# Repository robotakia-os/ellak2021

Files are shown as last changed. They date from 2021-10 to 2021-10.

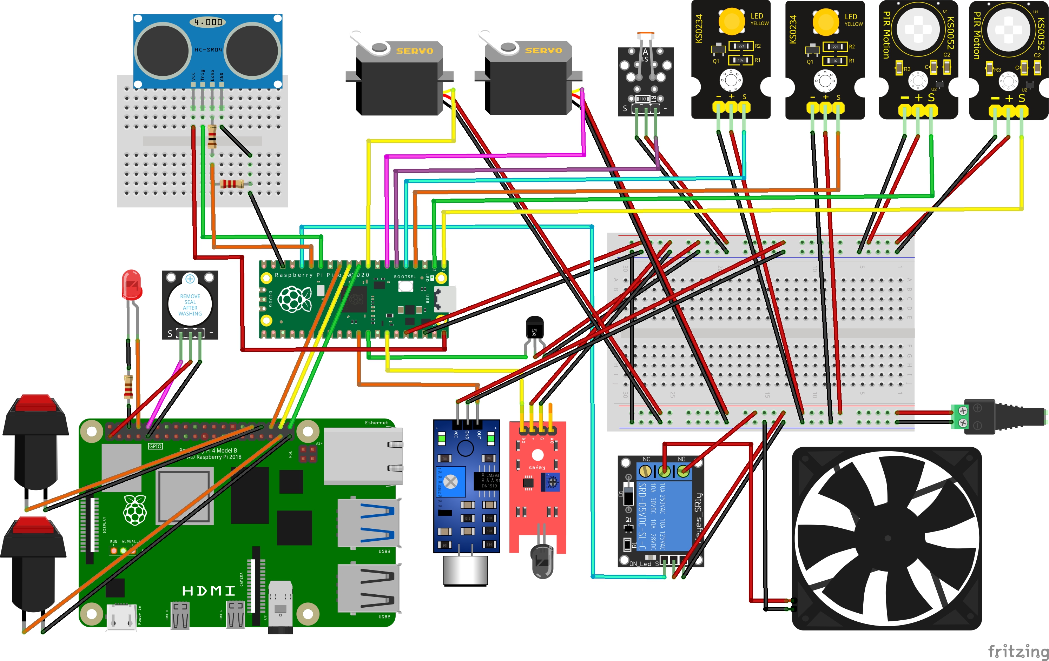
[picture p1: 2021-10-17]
σχηματικό-συνδεσμολογία/schematic.jpg

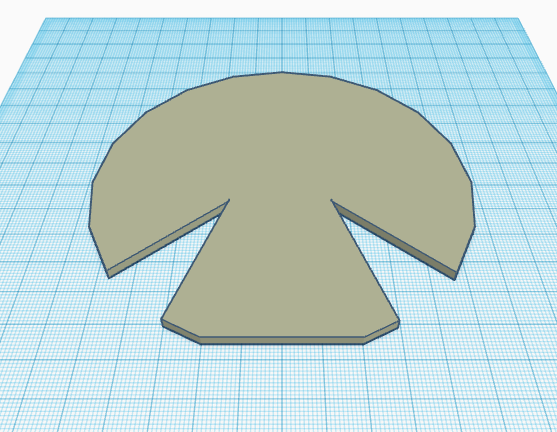
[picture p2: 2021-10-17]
3d printing/plate.png

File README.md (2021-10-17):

# ellak2021
3ος Πανελλήνιος Διαγωνισμός Ανοιχτών Τεχνολογιών στην Εκπαίδευση (2021)

Η ομάδα μας υλοποίησε μία μακέτα ενός ευφυούς σπιτιού φιλικό προς τα κατοικίδια. Στην εργασία περιλαμβάνονται οι παρακάτω προτάσεις/λύσεις:

•	Ενεργοποίηση του συστήματος φωτισμού σε συγκεκριμένους χώρους του σπιτιού και όταν αυτό κρίνεται απαραίτητο (μέρα/νύχτα).

•	Δημιουργία πόρτας διαφυγής του κατοικίδιου σε περίπτωση πυρκαγιάς.

•	Αναπαραγωγή χαλαρής μουσικής σε περίπτωση δυνατών ήχων που μπορεί να τρομάξουν το κατοικίδιο (βροντές κ.ά.).

•	Ενεργοποίηση εξαερισμού όταν η θερμοκρασία ανέβει σε υψηλά επίπεδα.

•	Σύστημα παροχής τροφής βασισμένο στην αναγνώριση αντικειμένων, το οποίο μπορεί να διακρίνει αν το κατοικίδιο είναι γάτα ή σκύλος. Το σύστημα ενεργοποιείται μόλις το κατοικίδιο πλησιάσει την τροφή του και σε προκαθορισμένα χρονικά διαστήματα.

•	Σύστημα συναγερμού το οποίο βασίζεται στην αναγνώριση αντικειμένων. Πιο συγκεκριμένα, ο συναγερμός ενεργοποιείται μόλις κάποιος άνθρωπος καταγραφεί από την κάμερα του συστήματος και όχι από κάποιον αισθητήρα PIR.

Η ιστοσελίδα του έργου μας: https://openedtech.ellak.gr/robotics2021/robotakia-open-source-effies-spiti-filiko-pros-ta-katikidia/

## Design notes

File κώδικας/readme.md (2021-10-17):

Το αρχείο pico_code.py είναι αυτό που εκτελείται από το Raspberry Pi Pico και το αρχείο pi4_code.py εκτελείται  στο Raspberry Pi 4.

Ο κώδικας που τρέχει στο Pico δημιουργήθηκε εξαρχής από την ομάδα μας. Αν μετονομαστεί το αρχείο σε main.py και αποθηκευτεί στο Pico και όχι στον υπολογιστή, θα τρέχει κατευθείαν μόλις το Pico τροφοδοτηθεί με 5V.

Στα αρχικά σχόλια του προγράμματος pi4_code.py περιγράφονται τα σημεία που τροποποιήσαμε τον κώδικα που χρησιμοποιήσαμε.

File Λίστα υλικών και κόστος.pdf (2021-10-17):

Το συνολικό κόστος υλοποίησης της μακέτας δεν ξεπερνά τα 100€, συμπεριλαμβανομένων των δευτερευόντων υλικών (μακετόχαρτα, θερμόκολλες κ.ά.) και όλα τα ηλεκτρονικά εξαρτήματα μπορούν να επαναχρησιμοποιηθούν σε μελλοντικό project. Το κόστος μπορεί να περιοριστεί ακόμα περισσότερο αν χρησιμοποιηθούν βασικότεροι αισθητήρες σε συνδυασμό με τα απαραίτητα ηλεκτρονικά στοιχεία (αντιστάτες, πυκνωτές κ.ά.) αντί για τις αντίστοιχες έτοιμες μονάδες (modules), κάτι που προτείνεται να γίνει στην περίπτωση που η εργασία υλοποιηθεί από μαθητές Λυκείου. Επιπλέον, η ομάδα μας επέλεξε να επαναχρησιμοποιήσει κάποια υλικά από παλιό υπολογιστή (ανεμιστήρας, επιπλέον καλωδιώσεις, 2 buttons) και διαθέταμε ήδη μία απλή USB κάμερα και ένα τροφοδοτικό 5V/1500mA.

Λίστα υλικών και κόστος

- Raspberry Pi 4 (2Gb): 44,9 €
- Raspberry Pi Pico: 4,5€
- Ultrasonic sensor: 1,6 €
- 2 x Micro Servo: 8 €
- LDR module: 2 €
- 2 x 3W LED module: 3,8 €
- 2 x PIR module: 5,6 €
- Red LED: 0,2 €
- Active Buzzer module: 1,4 €
- LM35 temperature sensor: 1,5 €
- Sound sensor: 1,9 €
- Flame sensor: 2 €
- Relay module: 2 €
- 3 x Resistors: 0,2 €
- Καλώδια: 5 €

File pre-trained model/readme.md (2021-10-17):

Το αρχείο περιλαμβάνει το μοντέλο MobileNet V1 που έχει εκπαιδευτεί στο σύνολο δεδομένων COCO ως μοντέλο ανίχνευσης αντικειμένων.

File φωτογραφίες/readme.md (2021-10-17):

Περιλαμβάνονται φωτογραφίες που λήφθηκαν κατά τη δημιουργία της μακέτας.

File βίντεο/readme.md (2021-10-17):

Μπορείτε να δείτε το βίντεο με την παρουσίαση της κατασκευής ακολουθώντας τον παρακάτω σύνδεσμο:

https://youtu.be/Yslna0o7fbs

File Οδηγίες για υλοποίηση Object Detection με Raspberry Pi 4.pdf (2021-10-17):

Για την ανίχνευση αντικειμένων (Object Detection) χρησιμοποιείται το πλαίσιο (framework) TensorFlow Lite και ένα προεκπαιδευμένο (pre-trained) μοντέλο Single Shot MultiBox Detector (SSD). Για το σκοπό αυτό, μπορεί να χρησιμοποιηθεί η Raspberry Pi Camera ή μια κοινή USB κάμερα. Ενεργοποιούμε το Raspberry Pi 4 και στο τερματικό του τρέχουμε τις εντολές που ακολουθούν.

Για να χρησιμοποιήσουμε τις εντολές python και pip με την έκδοση Python 3 και όχι την Python 2 πληκτρολογούμε:
cd ~
nano .bashrc

Όπως φαίνεται στη εικόνα που ακολουθεί, στο τέλος του κειμένου προσθέτουμε:
alias python=python3
alias pip=pip3

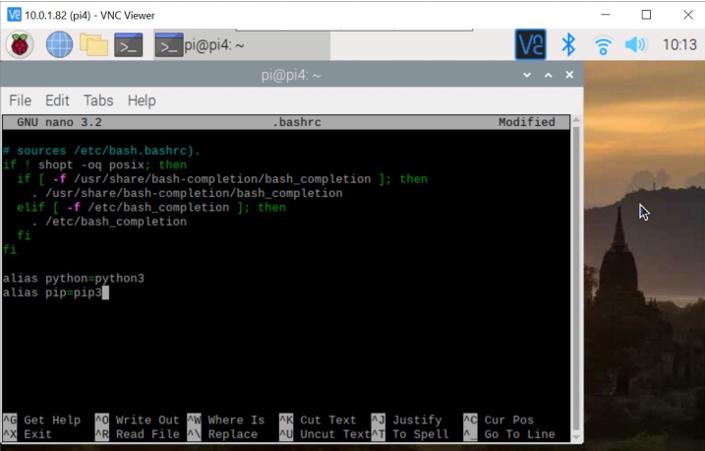
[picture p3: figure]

Κάνουμε save και exit (ctrl-x). Για να μην χρειαστεί να ανοίξουμε ξανά το τερματικό κάνουμε reload με την εντολή:
source .bashrc

Μπορούμε να επιβεβαιώσουμε την έκδοση της Python με την εντολή:
python --version

Θα δημιουργήσουμε ένα εικονικό περιβάλλον (virtual environment) για να διατηρήσουμε τις εγκατεστημένες βιβλιοθήκες και τα πακέτα απομονωμένα. Το TensorFlow Lite μπορεί να απαιτεί πολύ συγκεκριμένες εκδόσεις βιβλιοθηκών, οπότε ένα εικονικό περιβάλλον βοηθά να τις κρατήσουμε ξεχωριστά από το υπόλοιπο σύστημα. Αυτό θα το κάνουμε εγκαθιστώντας το virtualenv και δημιουργώντας ένα περιβάλλον tflite στο directory του έργου μας.

Για να δημιουργήσουμε το μονοπάτι πληκτρολογούμε:
mkdir -p Projects/Python/tflite

Για να πάμε μέσα στον φάκελο που δημιουργήσαμε:
cd Projects/Python/tflite

Για την εγκατάσταση του virtualenv και το περιβάλλον tflite:
python -m pip install virtualenv
python -m venv tflite-env

Για να ενεργοποιήσουμε το εικονικό περιβάλλον:
source tflite-env/bin/activate

Αναμένουμε να δούμε την παρακάτω εικόνα στο τερματικό.

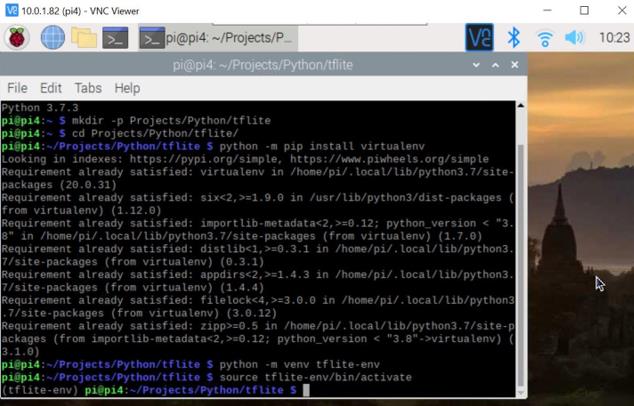
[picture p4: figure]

Προετοιμάζουμε το σύστημα για την εγκατάσταση των βιβλιοθηκών με μία ενημέρωση:
sudo apt-get update

Μέσα στο εικονικό περιβάλλον εγκαθιστούμε τις παρακάτω βιβλιοθήκες:
sudo | apt | -y | install | libjpeg-dev | libtiff5-dev | libjasper-dev | libpng12-dev
libavcodec-dev | libavformat-dev | libswscale-dev | libv4l-dev | libxvidcore-dev
libx264-dev qt4-dev-tools libatlas-base-dev libhdf5-103

Όταν ολοκληρωθεί η εγκατάσταση των παραπάνω θα χρησιμοποιήσουμε την εντολή pip για να εγκαταστήσουμε συγκεκριμένη έκδοση του OpenCV:
python -m pip install opencv-contrib-python==4.1.0.25

Αν και το Raspberry Pi 4 διαθέτει επεξεργαστή 64-bit, το προτεινόμενο λειτουργικό σύστημα Raspberry OS είναι 32-bit (τουλάχιστον μέχρι και τα τέλη του 2021 που γράφεται αυτός ο οδηγός). Μπορούμε να το επιβεβαιώσουμε αλλά και να δούμε την έκδοση της Python με τις εντολες:
uname -m
python --version

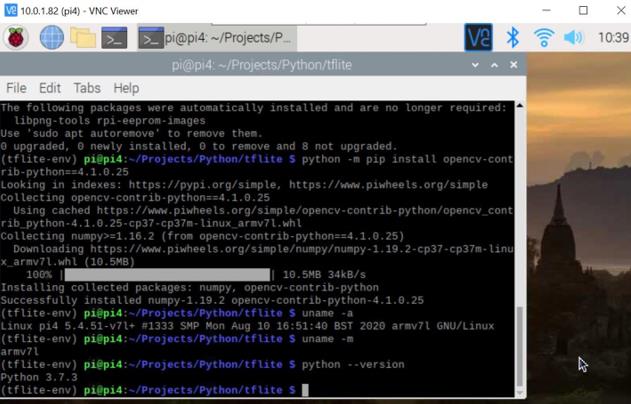
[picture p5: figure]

Στην παρακάτω εικόνα βλέπουμε την απόκριση arm7l που δηλώνει 32-bit και την έκδοση 3.7.3 για την Python.

Εγκαθιστούμε το TensorFlow Lite κατεβάζοντας το κατάλληλο αρχείο που στη συγκεκριμένη περίπτωση αντιστοιχεί στην έκδοση 32-bit:
pip3 | install | https://dl.google.com/coral/python/tflite_runtime-2.1.0.post1-
cp37-cp37m-linux_armv7l.whl

Απενεργοποιούμε το εικονικό περιβάλλον με την εντολή:
deactivate

Θα χρησιμοποιήσουμε ένα pre-trained μοντέλο αξιοποιώντας το Common Objects in Context (COCO) dataset. Περιλαμβάνει μια μεγάλη συλλογή εικόνων που έχουν επισημανθεί (tagged και labeled) από ερευνητές της Microsoft, και διάφορων πανεπιστημίων. Περιέχει πάνω από 200.000 εικόνες και περίπου 90 κατηγορίες αντικειμένων. Τα μοντέλα ανίχνευσης αντικειμένων ή ταξινόμησης αντικειμένων μπορούν να εκπαιδευτούν στο σύνολο δεδομένων COCO για να μας δώσουν μια αφετηρία για την αναγνώριση αντικειμένων καθημερινής χρήσης, όπως άτομα, αυτοκίνητα, ποδήλατα, σκύλοι, γάτες κ.ά. Θα χρησιμοποιήσουμε το μοντέλο MobileNet V1 που έχει εκπαιδευτεί στο σύνολο δεδομένων COCO ως μοντέλο ανίχνευσης αντικειμένων.

Δημιουργούμε το μονοπάτι:
mkdir -p ~/Projects/Python/tflite/object_detection/coco_ssd_mobilenet_v1

Πάμε στον φάκελο:
cd ~/Projects/Python/tflite/object_detection

Κατεβάζουμε το αρχείο coco_ssd_mobilenet_v1_1.0_quant_2018_06_29.zip που βρίσκεται στη διεύθυνση https://github.com/robotakia-os/ellak2021/tree/main/pre-trained%20model και επιβεβαιώνουμε ότι βρίσκεται στον φάκελο των λήψεων.

Μετακινούμε το αρχείο και το αποσυμπιέζουμε με τις εντολές:
mv ~/Downloads/coco_ssd_mobilenet_v1_1.0_quant_2018_06_29.zip .
unzip coco_ssd_mobilenet_v1_1.0_quant_2018_06_29.zip -d coco_ssd_mobilenet_v1

Πληκτρολογούμε την επόμενη εντολή για να πάμε έναν φάκελο παραπάνω:
cd –

Βρισκόμαστε και πάλι στη θέση /Projects/Python/tflite και ενεργοποιούμε και πάλι το εικονικό περιβάλλον:
source tflite-env/bin/activate

Θα εγκαταστήσουμε βιβλιοθήκες που σχετίζονται με τα pins του Raspberry:
pip install Rpi.GPIO
pip install gpiozero

Επιπλέον θα εγκαταστήσουμε και τις βιβλιοθήκες που σχετίζονται με την αναπαραγωγή της μουσικής:
pip install pygame
sudo apt-get install git curl libsdl2-mixer-2.0-0

Πληκτρολογούμε την παρακάτω εντολή και κλείνουμε το τερματικό:
deactivate

O κώδικας που θα τρέχει στο Raspberry Pi 4 είναι το αρχείο pi4_code.py. Αφού κατεβάσουμε το συγκεκριμένο αρχείο με τον κώδικα από το GitHub, θα πρέπει να το βάλουμε στον φάκελο /Projects/Python/tflite/object_detection . Τελικά για να ενεργοποιήσουμε την αναγνώριση αντικειμένων από το Raspberry Pi 4 πληκτρολογούμε στο τερματικό 4 εντολές.

Αρχικά πάμε στον φάκελο:
cd ~/Projects/Python/tflite

Ενεργοποιούμε το εικονικό περιβάλλον:
source tflite-env/bin/activate

Πάμε στον φάκελο:
cd object_detection

Τρέχουμε το πρόγραμμα με την εντολή:
python pi4_code.py --modeldir=coco_ssd_mobilenet_v1

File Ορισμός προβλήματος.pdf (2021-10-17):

Λαμβάνοντας υπόψη ότι το θέμα του διαγωνισμού είναι η Τεχνητή Νοημοσύνη, σκεφτήκαμε να υλοποιήσουμε μία εργασία που θα εκμεταλλευόταν τη συγκεκριμένη τεχνολογία προς όφελος των κατοικίδιων ζώων. Προβληματιστήκαμε από το γεγονός ότι ο σχεδιασμός των σπιτιών είναι προσανατολισμένος στις ανάγκες των ανθρώπων, παρόλο που και τα κατοικίδια περνούν τη ζωή τους μέσα σε αυτά. Για παράδειγμα, ένας σκύλος είναι αναγκασμένος να παραμείνει στο σκοτάδι σε περίπτωση που ο ιδιοκτήτης του γυρίσει αργά τη νύχτα. Μία γάτα μπορεί να μείνει χωρίς τροφή ή να μην τρέφεται σε σωστά χρονικά διαστήματα, εκτός και αν ο συγκάτοικος άνθρωπος είναι παρόν. Σε περίπτωση πυρκαγιάς λόγω βραχυκυκλώματος ή άλλης αιτίας, τα ζώα εγκλωβίζονται εντός του σπιτιού που διαβιούν αν δεν ανοίξει έγκαιρα μία πόρτα διαφυγής. Κροτίδες, βροντές, εξατμίσεις και άλλες πηγές ήχων υπερβολικής έντασης τρομάζουν τα ζώα και μία χαλαρωτική μουσική θα μπορούσε να τα βοηθήσει να ηρεμίσουν σε περίπτωση απουσίας του ιδιοκτήτη.

Επιπλέον, ανακαλύψαμε ένα υπαρκτό το πρόβλημα των σύγχρονων συστημάτων συναγερμού που χρησιμοποιούν σαν βασικό αισθητήρα έναν PIR sensor (*). O αισθητήρας PIR μπορεί να διακρίνει την κίνηση και την υπέρυθρη ακτινοβολία που εκπέμπουν όχι μόνο οι άνθρωποι αλλά και τα κατοικίδια επειδή η θερμοκρασία τους διαφέρει ελάχιστα. Οι λύσεις που προτείνουν οι κατασκευαστές συναγερμών είναι κυρίως δύο: Η αντιστροφή και τοποθέτηση του PIR σε υψηλότερο σημείο ώστε να μην ανιχνεύονται οι κινήσεις των ζώων κοντά στο πάτωμα ή η μείωση της ευαισθησίας του αισθητήρα (αν είναι ρυθμιζόμενος). Στην πράξη αυτές οι λύσεις δεν λύνουν το πρόβλημα ολοκληρωτικά καθώς ο συναγερμός εξακολουθεί να ενεργοποιείται όταν το κατοικίδιο πηδάει ή ανεβαίνει σε κάποιο έπιπλο και επιπλέον πολλά κατοικίδια είναι μεγαλόσωμα και δεν είναι δυνατό να ρυθμιστεί ο αισθητήρας με τέτοια ακρίβεια που θα τα διακρίνει απ’τους ανθρώπους. Επίσης, κάποιες εταιρίες προτείνουν ως λύση την αποστολή εικόνων από τις κάμερες του σπιτιού στο smartphone του ιδιοκτήτη και απαιτούν από αυτόν να εντοπίσει την αιτία ενεργοποίησης του συναγερμού, αλλά και πάλι και το πρόβλημα παραμένει. Αναμενόμενα, πολλοί ιδιοκτήτες κατοικιών που διαθέτουν τέτοια συστήματα συναγερμού καταλήγουν να απενεργοποιούν τους συναγερμούς όταν φεύγουν, για να σταματήσουν την ενοχλητική και άσκοπη ενεργοποίησή τους λόγω των κατοικίδιων. Συνεπώς, με την παρούσα εργασία προτείνουμε την υλοποίηση ενός συναγερμού που βασίζεται στην αναγνώριση αντικειμένων και ενεργοποιείται αν κάποιος άνθρωπος περάσει μπροστά από μία κάμερα που βρίσκεται στο κατάλληλο σημείο.

(*)
https://support.ring.com/hc/en-gb/articles/115005073406-Pets-and-the-Ring-Alarm-Motion-Detectorshttps://ajax.systems/blog/what-is-pet-immunity-in-motion-detectors-an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

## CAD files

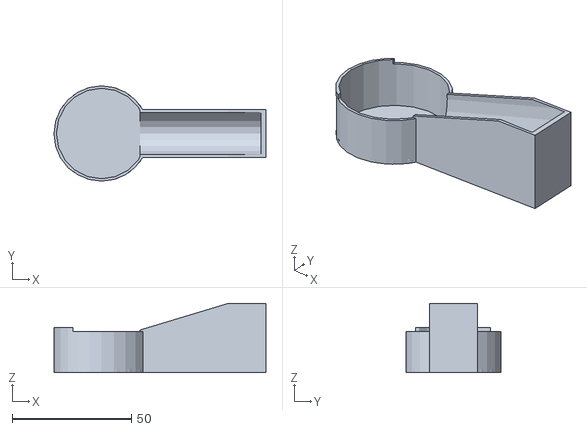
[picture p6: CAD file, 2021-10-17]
3d printing/feeder.stl
89.0 x 40.0 x 29.0

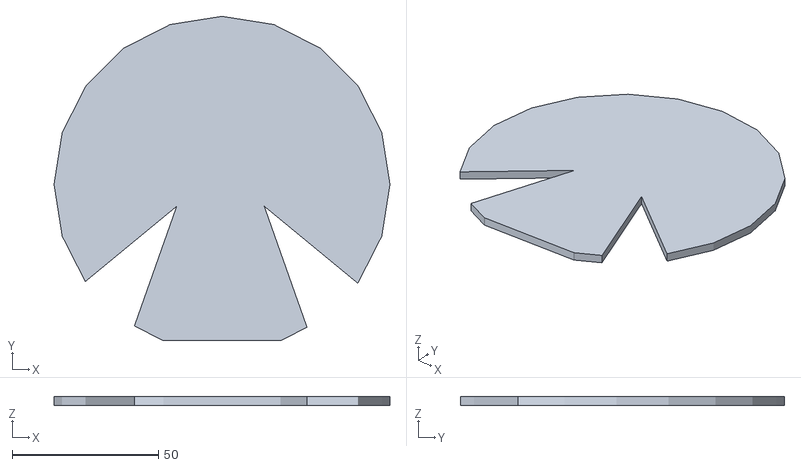
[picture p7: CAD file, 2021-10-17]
3d printing/plate.stl
115.0 x 111.0 x 3.00

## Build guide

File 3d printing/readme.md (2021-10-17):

Για τη δημιουργία του μηχανισμού παροχής τροφής χρησιμοποιήθηκε η πλατφόρμα Tinkercad.

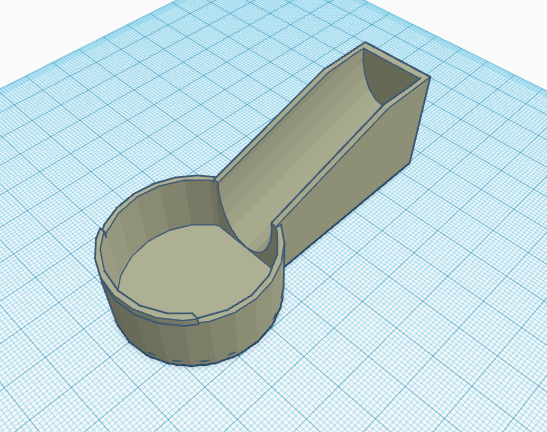
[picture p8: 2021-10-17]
3d printing/feeder.png

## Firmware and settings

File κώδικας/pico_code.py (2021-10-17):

from machine import Pin, ADC, PWM
from time import sleep, time, ticks_us, sleep_us

# δημιουργία αντικειμένων και δήλωση αριθμού pin
pir1Pin = Pin(0, Pin.IN, Pin.PULL_DOWN)   # PIR sensor
pir2Pin = Pin(1, Pin.IN, Pin.PULL_DOWN)   # PIR sensor
light1Pin = Pin(2, Pin.OUT)               # 3W LED
light2Pin = Pin(3, Pin.OUT)               # 3W LED
ldrPin = ADC(Pin(28))                     # LDR sensor
flamePin = Pin(4, Pin.IN, Pin.PULL_UP)    # flame sensor
doorServoPin = Pin(5, Pin.OUT)            # servo
foodServoPin = Pin(6, Pin.OUT)            # servo
pi4CatPin = Pin(8, Pin.IN, Pin.PULL_DOWN) # καλώδιο προς το Pi 4
pi4DogPin = Pin(7, Pin.IN, Pin.PULL_DOWN) # καλώδιο προς το Pi 4
triggerPin = Pin(10, Pin.OUT)             # ακροδέκτης trig του ultrasonic sensor
echoPin = Pin(11, Pin.IN)                 # ακροδέκτης echo του ultrasonic sensor
lm35Pin = ADC(Pin(27))                    # LM35 sensor
relayPin = Pin(12, Pin.OUT)               # έλεγχος ανεμιστήρα μέσω relay
micPin = ADC(Pin(26))                     # sound sensor
pi4MusicPin = Pin(9, Pin.OUT)             # καλώδιο προς το Pi 4

# ορισμός αρχικών τιμών σε μεταβλητές
catTimer = 0
dogTimer = 0
catFeedTime = 0
dogFeedTime = 0

def rotateServo(degrees, servo):            # δημιουργία συνάρτησης για την κίνηση των servo
    pwm = PWM(servo)                        # δημιουργία αντικειμένου pwm της κλάσης PWM
    pwm.freq(50)                            # συχνότητα 50Hz, συνεπώς 50 παλμοί/s
    # κατασκευή συνάρτησης με δεδομένα: 2,7ms->180μοίρες, 1,6ms->90μοίρες
    pulse_width = (0.012 * degrees + 0.54)  # πλάτος παλμού σε milliseconds
    pulse_width = pulse_width * 1000000     # πλάτος παλμού σε nanoseconds
    pulse_width = int(pulse_width)          # μετατροπή float σε int
    return pwm.duty_ns(pulse_width)         # επιστροφή τιμής στο κυρίως πρόγραμμα

def ultrasonic():                           # δημιουργία συνάρτησης για τη μέτρηση απόστασης
    global distance                         # η μεταβλητή distance είναι διαθέσιμη παντού
    timepassed = 0                          # ορισμός αρχικής τιμής
    signalon = 0                            # ορισμός αρχικής τιμής
    signaloff = 0                           # ορισμός αρχικής τιμής
    
    triggerPin.low()                        # δεν αποστέλεται υπέρηχος
    sleep_us(2)                             # διάρκεια σιγής 2μs
    triggerPin.high()                       # αποστολή υπέρηχου 
    sleep_us(5)                             # διάρκεια σήματος 5μs
    triggerPin.low()
    while echoPin.value() == 0:             # μη ανίχνευση ανακλώμενου υπέρηχου
        signaloff = ticks_us()
    while echoPin.value() == 1:             # ανίχνευση ανακλώμενου υπέρηχου
        signalon = ticks_us()
    timepassed = signalon - signaloff       # υπολογισμος χρονικής διάρκειας
    #s=v*t όπου v η ταχύτητα του υπέρηχου, και /2 γιατί ο υπέρηχος διανύει 2 φορές την απόσταση
    distance = (timepassed * 0.0343) / 2
    return distance                         # επιστροφή τιμής (σε cm) στο κυρίως πρόγραμμα

while True:
    ldr = ldrPin.read_u16()      # αναλογική ανάγνωση σήματος αισθητήρα φωτός
    sleep(0.01)                  # μικρή καθυστέρηση για να μετραπεί το σήμα σε ψηφιακό από τον ADC
    pir1 = pir1Pin.value()       # ψηφιακή ανάγνωση του ενός PIR
    pir2 = pir2Pin.value()       # ψηφιακή ανάγνωση του άλλου PIR
    # ενεργοποίηση φωτισμού στο πρώτο δωμάτιο αν δώσει σήμα ο PIR και ο φωτισμός είναι χαμηλός
    if pir1 == 1 and ldr < 15000:
        light1Pin.on()
    else:
        light1Pin.off()
    # ενεργοποίηση φωτισμού στο δεύτερο δωμάτιο αν δώσει σήμα ο PIR και ο φωτισμός είναι χαμηλός
    if pir2 == 1 and ldr < 15000:
        light2Pin.on()
    else:
        light2Pin.off()

    flame = flamePin.value()           # ψηφιακή ανάγνωση του flame sensor
    # περιστροφή servo 140 μοίρες και άνοιγμα πόρτας διαφυγής σε περιπτωση πυρκαγιάς
    if flame == 0:
        rotateServo(140, doorServoPin)
    else:
        rotateServo(0, doorServoPin)

    ultrasonic()             # κλήση της συνάρτησης που επιστρέφει την καταγεγραμμένη απόσταση 
    cat = pi4CatPin.value()  # το Raspberry Pi 4 θα στείλει 1 αν εντοπιστεί γάτα, διαφορετικά 0
    dog = pi4DogPin.value()  # το Raspberry Pi 4 θα στείλει 1 αν εντοπιστεί σκύλος, διαφορετικά 0

    currentTime = time()     # βοηθητική μεταβλητή για να υπολογιστεί αργότερα ο χρόνος που κύλησε
    # γάτα και σκύλος θα φάνε αν εντοπιστούν, πλησιάσουν κοντά και περάσουν 10s από την τελευταία φορά
    if cat == 1 and catTimer > 10 and distance < 20:
        rotateServo(135, foodServoPin) # περιστροφή μηχανισμού δεξιόστροφα για το φαγητό της γάτας
        sleep(0.5)                     # διάρκεια πτώσης τροφής
        rotateServo(90, foodServoPin)  # επιστροφή μηχανισμού στην αρχική θέση
        catFeedTime = time()           # καταγραφή χρονικής στιγμής που έφαγε η γάτα
        cat = 0                        # θα ξαναγίνει 1 όταν ξαναδεί τη γάτα η κάμερα
    elif dog == 1 and dogTimer > 10 and distance < 20:
        rotateServo(45, foodServoPin)  # περιστροφή μηχανισμού αριστερόστροφα για το φαγητό του σκύλου
        sleep(0.5)                     # διάρκεια πτώσης τροφής
        rotateServo(90, foodServoPin)  # επιστροφή μηχανισμού στην αρχική θέση
        dogFeedTime = time()           # καταγραφή χρονικής στιγμής που έφαγε ο σκύλος
        dog = 0                        # θα ξαναγίνει 1 όταν ξαναδεί τον σκύλο η κάμερα
    else:
        rotateServo(90, foodServoPin)  # ο μηχανισμός δεν επιτρέπει σε καμία τροφή να πέσει
    
    catTimer = currentTime - catFeedTime # υπολογισμός χρόνου απ' όταν έφαγε για τη γάτα
    dogTimer = currentTime - dogFeedTime # υπολογισμός χρόνου απ' όταν έφαγε για ο σκύλος
    
    temp = 0                         # βοηθητική μεταβλητή για την εξαγωγή του μέσου όρου 10 μετρήσεων
    for i in range(10):              # εξαγωγή μέσου όρου για να προκύψουν σταθερότερες τιμές
        lm35 = lm35Pin.read_u16()    # αναλογική ανάγνωση σήματος αισθητήρα θερμοκρασίας
        sleep(0.01)                  # μικρή καθυστέρηση για να μετραπεί το σήμα σε ψηφιακό από τον ADC
        # voltage/3.3 = lm35/65535 -> voltage = (3.3/65535)*lm35
        voltage = (3.3/65535) * lm35 # μετατροπή τιμής σήματος σε τιμή τάσης
        # Για τον LM35 ισχύει: temperature/1 = voltage/0,01 -> temperature = voltage*100
        temperature = voltage * 100  # μετατροπή τιμής τάσης σε τιμή θερμοκρασίας σε βαθμούς Κελσίου
        temp = temp + temperature    # η καινούρια μέτρηση προστίθεται στην παλιά
    temp = temp / 10                 # διαίρεση με το 10 για να προκύψει ο μέσος όρος 
    # ενεργοποίηση ανεμιστήρα μέσω του relay αν η θερμοκρασία είναι υψηλή
    if temp > 32:
        relayPin.on()
    else:
        relayPin.off()
    
    micValue = micPin.read_u16()     # αναλογική ανάγνωση σήματος αισθητήρα ήχου
    sleep(0.01)                      # μικρή καθυστέρηση για να μετραπεί το σήμα σε ψηφιακό από τον ADC
    # αποστολή 1 ή 0 προς το Raspberry Pi 4 αν η ένταση του ήχου ξεπεράσει κάποιο κατώφλι
    if micValue > 20000:
        pi4MusicPin.on()
        sleep(0.5)
    else:
        pi4MusicPin.off()
    # εμφάνιση τιμών θερμοκρασίας στην οθόνη του υπολογιστή (αν επιλέξουμε να τον συνδέσουμε στο Pico)
    print(temp) 

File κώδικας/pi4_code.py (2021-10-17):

# Author: Evan Juras
# Date: 10/27/19
# Description: 
# This program uses a TensorFlow Lite model to perform object detection on a live webcam
# feed. It draws boxes and scores around the objects of interest in each frame from the
# webcam. To improve FPS, the webcam object runs in a separate thread from the main program.
# This script will work with either a Picamera or regular USB webcam.
# This code is based off the TensorFlow Lite image classification example at:
# https://github.com/tensorflow/tensorflow/blob/master/tensorflow/lite/examples/python/label_image.py
# I added my own method of drawing boxes and labels using OpenCV.
# 
# Modified by: Shawn Hymel
# Date: 09/22/20
# Description:
# Added ability to resize cv2 window and added center dot coordinates of each detected object.
# Objects and center coordinates are printed to console.
#
# Τροποποιήθηκε από: Robotakia Open Source
# Ημερομηνία: 17/10/21
# Περιγραφή:
# Προστέθηκε η δυνατότητα αναπαραγωγής μουσικής και ένα κουμπί για τη διακοπή της και 
# η δυνατότητα ενεργοποίησης/απενεργοποίσης μέσω ενός κουμπιού του συναγερμού που
# αποτελείται από ένα LED και ένα Buzzer. Επιπλέον, γίνεται εξαγωγή της πληροφορίας αν το
# αντικείμενο που ανιχνεύτηκε είναι cat, dog ή person για να ακολουθήσουν οι επιθυμητές
# ενέργειες. Οι προσθήκες που πραγματοποιήσαμε βρίσκονται στις σειρές 36-48 και 245-275.

# Import packages
import os
import argparse
import cv2
import numpy as np
import sys
import time
from threading import Thread
import importlib.util
from gpiozero import OutputDevice, DigitalInputDevice, Button, LED, Buzzer # εισαγωγή βιβλιοθηκών που σχετίζονται με τον έλεγχο των pins
from pygame import mixer # απαραίτητη βιβλιοθήκη για την αναπαραγωγή μουσικής

stopMusicButton = Button(12)          # κουμπί για τη διακοπή της μουσικής
alarmButton = Button(26)              # κουμπί ενεργοποίησης/απενεργοποίσης του συναγερμού
ledPin = LED(14)                      # LED συναγερμού
buzzerPin = Buzzer(15)                # ηχητική ειδοποίηση συναγερμού
picoDogPin = OutputDevice(21)         # καλώδιο προς το Pico
picoCatPin = OutputDevice(20)         # καλώδιο προς το Pico
picoMusicPin = DigitalInputDevice(16) # καλώδιο προς το Pico

mixer.init()                          # αρχικοποίηση λειτουργιών μουσικής
alarm = False                         # αρχικά ο συναγερμός είναι απενεργοποιημένος

# Define VideoStream class to handle streaming of video from webcam in separate processing thread
# Source - Adrian Rosebrock, PyImageSearch: https://www.pyimagesearch.com/2015/12/28/increasing-raspberry-pi-fps-with-python-and-opencv/
class VideoStream:
    """Camera object that controls video streaming from the Picamera"""
    def __init__(self,resolution=(640,480),framerate=30):
        # Initialize the PiCamera and the camera image stream
        self.stream = cv2.VideoCapture(0)
        ret = self.stream.set(cv2.CAP_PROP_FOURCC, cv2.VideoWriter_fourcc(*'MJPG'))
        ret = self.stream.set(3,resolution[0])
        ret = self.stream.set(4,resolution[1])
            
        # Read first frame from the stream
        (self.grabbed, self.frame) = self.stream.read()

    # Variable to control when the camera is stopped
        self.stopped = False

    def start(self):
    # Start the thread that reads frames from the video stream
        Thread(target=self.update,args=()).start()
        return self

    def update(self):
        # Keep looping indefinitely until the thread is stopped
        while True:
            # If the camera is stopped, stop the thread
            if self.stopped:
                # Close camera resources
                self.stream.release()
                return

            # Otherwise, grab the next frame from the stream
            (self.grabbed, self.frame) = self.stream.read()

    def read(self):
    # Return the most recent frame
        return self.frame

    def stop(self):
    # Indicate that the camera and thread should be stopped
        self.stopped = True

# Define and parse input arguments
parser = argparse.ArgumentParser()
parser.add_argument('--modeldir', help='Folder the .tflite file is located in',
                    required=True)
parser.add_argument('--graph', help='Name of the .tflite file, if different than detect.tflite',
                    default='detect.tflite')
parser.add_argument('--labels', help='Name of the labelmap file, if different than labelmap.txt',
                    default='labelmap.txt')
parser.add_argument('--threshold', help='Minimum confidence threshold for displaying detected objects',
                    default=0.5)
parser.add_argument('--resolution', help='Desired webcam resolution in WxH. If the webcam does not support the resolution entered, errors may occur.',
                    default='1280x720')
parser.add_argument('--edgetpu', help='Use Coral Edge TPU Accelerator to speed up detection',
                    action='store_true')

args = parser.parse_args()

MODEL_NAME = args.modeldir
GRAPH_NAME = args.graph
LABELMAP_NAME = args.labels
min_conf_threshold = float(args.threshold)
resW, resH = args.resolution.split('x')
imW, imH = int(resW), int(resH)
use_TPU = args.edgetpu

# Import TensorFlow libraries
# If tflite_runtime is installed, import interpreter from tflite_runtime, else import from regular tensorflow
# If using Coral Edge TPU, import the load_delegate library
pkg = importlib.util.find_spec('tflite_runtime')
if pkg:
    from tflite_runtime.interpreter import Interpreter
    if use_TPU:
        from tflite_runtime.interpreter import load_delegate
else:
    from tensorflow.lite.python.interpreter import Interpreter
    if use_TPU:
        from tensorflow.lite.python.interpreter import load_delegate

# If using Edge TPU, assign filename for Edge TPU model
if use_TPU:
    # If user has specified the name of the .tflite file, use that name, otherwise use default 'edgetpu.tflite'
    if (GRAPH_NAME == 'detect.tflite'):
        GRAPH_NAME = 'edgetpu.tflite'       

# Get path to current working directory
CWD_PATH = os.getcwd()

# Path to .tflite file, which contains the model that is used for object detection
PATH_TO_CKPT = os.path.join(CWD_PATH,MODEL_NAME,GRAPH_NAME)

# Path to label map file
PATH_TO_LABELS = os.path.join(CWD_PATH,MODEL_NAME,LABELMAP_NAME)

# Load the label map
with open(PATH_TO_LABELS, 'r') as f:
    labels = [line.strip() for line in f.readlines()]

# Have to do a weird fix for label map if using the COCO "starter model" from
# https://www.tensorflow.org/lite/models/object_detection/overview
# First label is '???', which has to be removed.
if labels[0] == '???':
    del(labels[0])

# Load the Tensorflow Lite model.
# If using Edge TPU, use special load_delegate argument
if use_TPU:
    interpreter = Interpreter(model_path=PATH_TO_CKPT,
                              experimental_delegates=[load_delegate('libedgetpu.so.1.0')])
    print(PATH_TO_CKPT)
else:
    interpreter = Interpreter(model_path=PATH_TO_CKPT)
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
